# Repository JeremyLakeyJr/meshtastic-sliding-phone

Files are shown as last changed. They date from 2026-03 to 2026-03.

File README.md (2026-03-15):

# Meshtastic Sliding Phone

A 3D-printable sliding phone enclosure for **Meshtastic** mesh networking devices. This design houses a **Heltec WiFi LoRa 32 V4** board and a **M5Stack CardKB** I²C keyboard in a compact, pocket-friendly Nokia N900-style landscape slider. The keyboard tray slides along two rectangular guide rails on the interior side walls of the top shell, snapping into open and closed positions via offset neodymium magnet detents.

```
    ┌─────────────────────┐
    │  ╔═════════╗        │  ← Speaker grille
    │  ║ 0.96"   ║        │
    │  ║  OLED   ║        │  ← OLED viewport
    │  ╚═════════╝        │
    │     [PWR]  [VOL]    │  ← Side buttons
    ├─────────────────────┤  ← Rectangular rail guides (interior side walls)
    │  ┌─┐┌─┐┌─┐┌─┐┌─┐  │
    │  │Q││W││E││R││T│..  │  ← CardKB (revealed when slid open)
    │  └─┘└─┘└─┘└─┘└─┘  │
    │  ┌─┐┌─┐┌─┐┌─┐┌─┐  │
    │  │A││S││D││F││G│..  │
    │  └─┘└─┘└─┘└─┘└─┘  │
    │  [USB-C]    [ANT]   │  ← Ports
    └─────────────────────┘
```

## Features

- **Rectangular-rail slider** — two 3×3 mm rectangular guide rails on the interior side walls of the top shell constrain the keyboard tray; passive ~3° typing tilt at full extension
- **Offset magnetic detents** — 6× 10 mm × 4 mm neodymium disc magnets (4 in top shell, 2 in tray) snap audibly into closed and open positions via 6 mm lateral offset
- **0.96" OLED viewport** aligned with the Heltec V4's built-in 128×64 display
- **CardKB pocket** — snap-in slot for the M5Stack CardKB I²C keyboard module (88×54×7 mm)
- **LiPo battery** compartment (MakerFocus 3000 mAh or similar flat pouch cell, ~71×51×9 mm) integrated in the top shell
- **SMA antenna mount** with strain relief for LoRa whip antenna
- **USB-C port** access for charging and firmware flashing
- **Speaker grille & microphone** holes
- **Ventilation slots** for thermal management
- **M2 screw posts** for secure PCB mounting
- **Fully parametric** — all dimensions easily adjustable

## Improved CAD Generation Prompt

Use this prompt when generating enclosure concepts with AI CAD tools:

> Create a fully parametric, 3D-printable electronics enclosure optimized for FDM printing. Model separate printable parts (main shell, sliding tray, and mounting features), expose key dimensions as editable parameters (PCB size, battery size, wall thickness, clearances, and travel), and enforce print-safe geometry (minimum 2 mm walls, filleted/chamfered transitions, no unsupported overhangs beyond ~45°, and practical assembly tolerances). Include internal standoffs, cable-routing channels, ventilation, fastener or snap-fit options, and clear support for iterative dimension tuning without rewriting core geometry.

## Project Structure

```
meshtastic-sliding-phone/
├── models/
│   ├── scad/                    # OpenSCAD parametric source files
│   │   ├── parameters.scad      # Shared dimensions & tolerances
│   │   ├── utilities.scad       # Reusable shape modules (rails, magnets, etc.)
│   │   ├── top_shell.scad       # Unified top enclosure: OLED viewport, PCB bay, battery, rails
│   │   ├── keyboard_tray.scad   # Sliding keyboard tray: CardKB pocket, rail grooves, magnets
│   │   ├── bottom_shell.scad    # Alias for keyboard_tray.scad (2-piece naming)
│   │   ├── main_body.scad       # Backward-compatible alias for top_shell.scad
│   │   ├── antenna_mount.scad   # SMA connector mount with strain relief
│   │   └── assembly.scad        # Full exploded/assembled preview (not for printing)
│   └── stl/                     # Pre-generated printable meshes
│       ├── top_shell.stl
│       ├── keyboard_tray.stl
│       └── antenna_mount.stl
├── scripts/
│   └── generate_stl.py          # Python STL generator (no OpenSCAD needed; approximate)
├── docs/
│   └── bill_of_materials.md     # Parts list & sourcing guide
└── README.md
```

## Hardware Compatibility

| Component | Specification |
|---|---|
| **Main board** | Heltec WiFi LoRa 32 V4 (ESP32-S3 + SX1262 LoRa + 0.96" OLED) |
| **Display** | Built-in 0.96" OLED 128×64 (on Heltec V4 PCB) |
| **Keyboard** | M5Stack CardKB v1.1 (I²C, 88×54×7 mm, 46-key QWERTY) |
| **Battery** | MakerFocus 3.7 V LiPo 3000 mAh (~71×51×9 mm nominal) |
| **Antenna** | SMA LoRa antenna (868/915 MHz) |
| **Fasteners** | M2×8mm screws + M2 nuts |

## Dimensions

| Part | Width (X) | Length (Y) | Height (Z) |
|---|---|---|---|
| Top Shell | 95 mm | 120 mm | 19 mm |
| Keyboard Tray (Bottom Shell) | 95 mm | 120 mm | 8 mm |
| Antenna Mount | 16 mm | 12 mm | 10 mm |
| **Assembled (closed)** | **95 mm** | **120 mm** | **27 mm** |

Slider travel: **65 mm** (exposes full 54 mm CardKB short axis + margin)

## Getting Started

### Option 1: Use Pre-generated STL Files

The `models/stl/` directory contains ready-to-print STL files. Import them into your slicer (PrusaSlicer, Cura, etc.) and print.

### Option 2: Customize with OpenSCAD

1. Install [OpenSCAD](https://openscad.org/downloads.html)
2. Open any `.scad` file from `models/scad/`
3. Edit `parameters.scad` to adjust dimensions for your hardware
4. Render and export as STL

```bash
# Render individual parts from command line
openscad -o top_shell.stl models/scad/top_shell.scad
openscad -o keyboard_tray.stl models/scad/keyboard_tray.scad
openscad -o antenna_mount.stl models/scad/antenna_mount.scad
```

### Option 3: Generate STL with Python

No OpenSCAD required — uses `numpy-stl` for mesh generation:

```bash
pip install numpy-stl numpy
python3 scripts/generate_stl.py              # Generate all parts
python3 scripts/generate_stl.py --part top_shell  # Generate one part
```

## Print Settings

| Setting | Recommendation |
|---|---|
| **Layer Height** | 0.2mm (0.12mm for OLED viewport frame) |
| **Infill** | 20–25% top shell, 30% keyboard tray |
| **Material** | PETG or ASA recommended (PLA acceptable) |
| **Supports** | Not required — all overhangs ≤ 45°; rectangular groove walls need no support |
| **Orientation** | Top shell: display face down; keyboard tray: top face (grooves) down |
| **Walls** | 3 perimeters minimum |

## Assembly Instructions

1. **Print all parts** using recommended settings above
2. **Press-fit magnets** — press 6× 10 mm × 4 mm neodymium disc magnets into their pockets (check polarity: opposing pairs must attract). Top shell has 4 pockets (2 for closed snap at X=+38 mm, 2 for open snap at X=−39 mm); keyboard tray has 2 pockets at X=+32 mm.
3. **Seat the CardKB** — press the M5Stack CardKB module into the pocket in the keyboard tray; the retention ledges click it in place
4. **Mount the Heltec V4** — secure with M2×8mm screws through the 4 mounting posts inside the top shell; align the OLED with the viewport window
5. **Wire the CardKB** — run the CardKB I²C cable through the side access slot and connect to the Heltec V4 (SDA → GPIO 21, SCL → GPIO 22); use the wire routing groove alongside the rail
6. **Install the antenna mount** — attach to the top edge of the top shell with M2 screws, thread the SMA connector through
7. **Insert the LiPo battery** — place the flat LiPo cell in the battery compartment inside the top shell and snap the retention clips
8. **Assemble the slide** — align the keyboard tray's rail grooves with the top shell's rectangular rails at the **+X (right) end** and slide the tray in; it will snap into the closed position via the magnet detents
9. **Flash Meshtastic firmware** — connect via USB-C and use [flasher.meshtastic.org](https://flasher.meshtastic.org); select **Heltec WiFi LoRa 32 V4** as the target device

## Customization

All dimensions are parametric. Edit `models/scad/parameters.scad` to adjust:

- `phone_length`, `phone_width` — overall body footprint
- `wall_thickness` / `wall` — shell wall thickness (increase for durability)
- `clearance` — general sliding-fit tolerance (tune for your printer)
- `slider_travel` / `keyboard_travel` — how far the keyboard tray slides out (default 65 mm)
- `rail_width`, `rail_height` — rectangular guide rail cross-section (3×3 mm default)
- `rail_clearance` — per-side clearance between rail and tray groove (0.35 mm default)
- `rail_length` — guide rail length along X (70 mm default, ≥70% of tray width)
- `channel_standoff` — extra groove depth for passive typing tilt (2 mm → ~3° tilt)
- `magnet_offset` — lateral offset between body and tray magnet pockets for snap-in detent (6 mm)
- `corner_radius` — roundness of edges
- `cardkb_w`, `cardkb_h`, `cardkb_thickness` — CardKB module pocket dimensions
- PCB, battery, display viewport dimensions — match your specific hardware

## Contributing

Contributions welcome! Please:
- Test-print modified designs before submitting
- Update `parameters.scad` comments for new dimensions
- Include photos of printed parts if possible

## License

This project is open source. See individual files for details.

## Acknowledgments

- [Meshtastic](https://meshtastic.org/) — open-source mesh networking
- [Heltec Automation](https://heltec.org/) — WiFi LoRa 32 V4 hardware
- [M5Stack](https://m5stack.com/) — CardKB keyboard module
- OpenSCAD and numpy-stl communities

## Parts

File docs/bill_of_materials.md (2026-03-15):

# Bill of Materials — Meshtastic Sliding Phone

## Electronics

| Qty | Component | Specification | Notes |
|-----|---|---|---|
| 1 | Heltec WiFi LoRa 32 V4 | ESP32-S3 + SX1262 LoRa + built-in 0.96" OLED, 7 capacitive touch pins | Main controller board (51.7 × 25.4 mm, ≈52 × 26 mm) |
| 1 | M5Stack CardKB v1.1 | I²C QWERTY keyboard, 88×54×7 mm, 3.3 V/5 V | Connects to Heltec V4 via I²C (SDA/SCL) |
| 1 | LiPo Battery | 3.7 V, MakerFocus 3000 mAh flat pouch ~71×51×9 mm | JST PH 2.0 or JST 1.25 mm 2-pin connector |
| 1 | LoRa Antenna | SMA, 868 MHz or 915 MHz (region-dependent) | Stubby or flexible whip style |
| 1 | GPS Antenna | IPX/U.FL ceramic patch | Optional — Heltec V4 has no on-board GPS |

## Sliding Mechanism — Neodymium Disc Magnets

Six magnets total; install with poles oriented so opposing pairs **attract**.
Verify orientation before pressing in: wrong polarity will repel instead of snap.

| Qty | Component | Specification | Location |
|-----|---|---|---|
| 4 | Neodymium disc magnet | **10 mm dia × 4 mm thick, N35 grade** | Top shell — 2 × closed-snap pockets (body X=+38 mm), 2 × open-snap pockets (body X=−39 mm) |
| 2 | Neodymium disc magnet | **10 mm dia × 4 mm thick, N35 grade** | Keyboard tray — 2 × detent pockets (tray X=+32 mm) |

> **Magnet pocket spec**: Each pocket bore is 10.3 mm diameter × 3.6 mm deep with a 0.6 mm retention lip
> (entrance narrows to 9.1 mm). Press the 10 mm magnet past the lip — the FDM wall deflects slightly
> and springs back, locking the magnet in place. The magnet sits 0.4 mm proud of the face for better
> magnetic contact with the opposing pocket.
>
> **Detent offset**: Top-shell pockets are displaced ±6 mm in the slide direction (X) relative to the
> tray pockets. This offset creates an X-component attraction force that actively pulls the tray into
> each snap position rather than just providing a Z-axis normal force.

## Mechanical

| Qty | Component | Specification | Notes |
|-----|---|---|---|
| 8 | M2×8 mm screws | Pan head, Phillips or hex socket | PCB mounting + shell join |
| 8 | M2 hex nuts | Standard | Or use heat-set inserts |
| 4 | M2 heat-set inserts | 3.5 mm OD × 4 mm length | Optional — replaces nuts |
| 1 | Silicone grease | Small tube, PTFE-based | Apply to rail runners for smooth sliding |

## 3D Printed Parts

| Qty | Part | File | Material | Infill | Supports |
|-----|---|---|---|---|---|
| 1 | Top Shell | `top_shell.scad` | PETG / ASA | 20–25% | No |
| 1 | Keyboard Tray | `keyboard_tray.scad` | PETG / ASA | 30% | No — print top face DOWN |
| 1 | Antenna Mount | `antenna_mount.scad` | PETG / ASA | 40% | No |

> `bottom_shell.scad` is an alias for `keyboard_tray.scad` — they produce the same part.
> `main_body.scad` is a backward-compatible alias for `top_shell.scad`.

### Print orientation notes
- **Top shell**: display face down — button recesses and viewport print cleanly without support.
- **Keyboard tray**: top face (rail grooves) down — rectangular groove walls print as clean vertical layers; zero support needed.

## Assembly sequence

1. Press-fit magnets into the top-shell pockets (4 magnets; check polarity — closed-snap pair at X=+38 mm must attract tray magnets when tray is in closed position).
2. Press-fit magnets into the keyboard-tray pockets (2 magnets; opposing pole faces upward toward top shell).
3. Apply a thin coat of PTFE grease to the rectangular guide rails on the top shell.
4. Slide the keyboard tray in from the **+X (right) end** of the top shell.
   Hold the phone landscape (120 mm wide, 95 mm tall) — the keyboard slides
   downward to expose the CardKB, Nokia N900-style.
5. Snap the tray closed — the magnetic click should be clearly perceptible.
6. Assemble electronics: mount Heltec V4 PCB (51.7 × 25.4 mm) onto the 4 standoffs with M2 screws,
   route I²C cable from CardKB through the wire-routing groove and side access slot.
7. Insert the MakerFocus LiPo battery (71×51×9 mm) into the battery pocket; the retention clips snap over the edges.
8. Attach antenna mount to the top edge of the top shell with M2 screws and thread the SMA connector through.

## Optional Add-ons

| Component | Purpose |
|---|---|
| Wrist strap loop | Attach lanyard/strap for field use |
| Belt clip adapter | Clip to belt or MOLLE webbing |
| Capacitive touch overlay | 23 × 13 mm panel over OLED viewport; wire to V4 touch pins |
| Screen protector film | Cut to 23×13 mm for OLED/touch viewport |
| Rubber bumpers (4×) | Stick-on feet for table use |
| USB-C cable (short) | Charging / firmware flash |
| External GPS module | Add GPS capability (Heltec V4 has no on-board GPS) |

## Sourcing

- **Heltec WiFi LoRa 32 V4**: [Heltec Official Store](https://heltec.org/project/wifi-lora-32-v4/)
- **M5Stack CardKB v1.1**: [M5Stack Official Store](https://shop.m5stack.com/products/cardkb-mini-keyboard-programmable-unit-v1-1-mega328p)
- **MakerFocus 3000 mAh LiPo**: Search for "MakerFocus 3000mAh 3.7V lipo 71×51mm" on Amazon
- **10 mm × 4 mm N35 magnets**: Amazon / AliExpress — search "10mm x 4mm neodymium disc magnets N35"
- **M2 hardware**: Amazon, McMaster-Carr, local hardware store
- **PETG filament**: Prusament, eSun, Hatchbox or equivalent

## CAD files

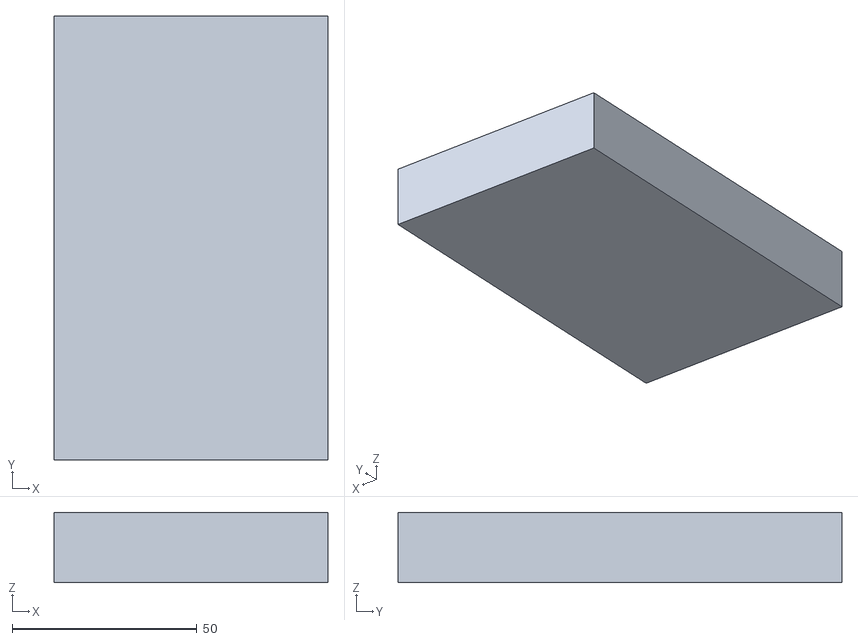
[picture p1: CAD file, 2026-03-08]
models/stl/main_body.stl
74.0 x 120.0 x 19.0

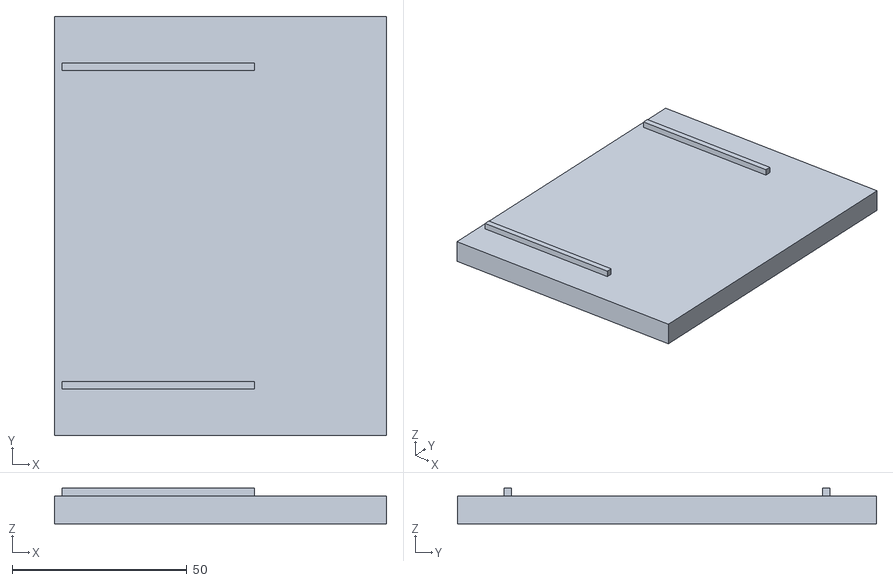
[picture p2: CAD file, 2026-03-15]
models/stl/keyboard_tray.stl
95.0 x 120.0 x 10.2

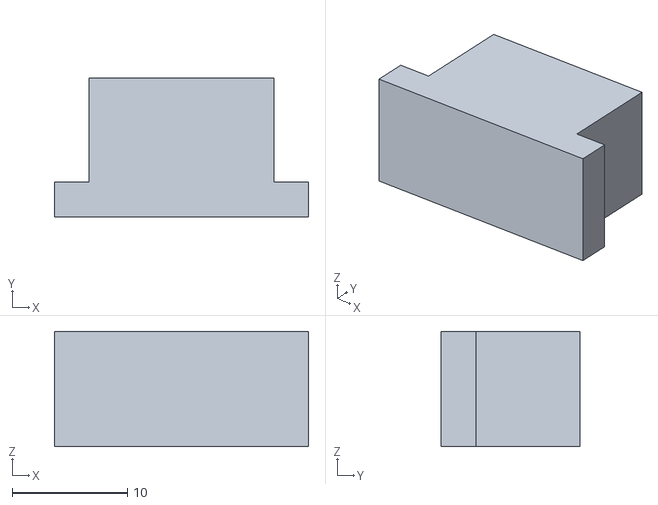
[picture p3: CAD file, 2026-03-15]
models/stl/antenna_mount.stl
22.0 x 12.0 x 10.0

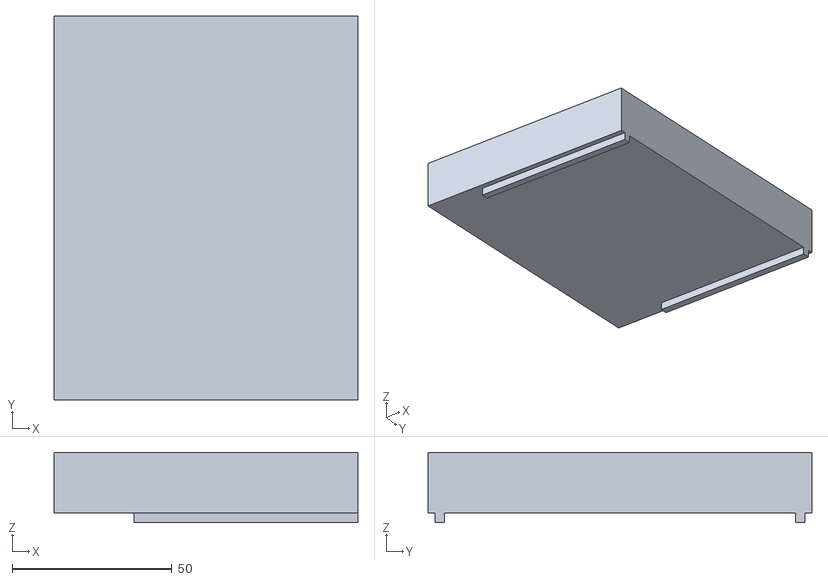
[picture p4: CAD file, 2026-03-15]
models/stl/top_shell.stl
95.0 x 120.0 x 22.0

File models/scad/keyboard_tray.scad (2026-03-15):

// ============================================================================
// Meshtastic Sliding Phone – Keyboard Tray  (sliding component / bottom shell)
// ============================================================================
// The horizontally sliding keyboard carriage.  Sits beneath the top shell
// and slides in the −X direction (shortways, along the 95 mm short axis) by
// slider_travel (65 mm) to expose the M5Stack CardKB module.  Holding the
// phone in landscape (120 mm wide × 95 mm tall) the keyboard slides downward.
//
// KEY FEATURES
// ─────────────────────────────────────────────────────────────────────────
// Slider rail grooves (capture the additive rails from the top shell)
//   The top shell carries two rectangular rails (rail_width × rail_height =
//   3 × 3 mm) on its interior side walls at Y = ±(phone_length/2 −
//   wall_thickness) = ±57.8 mm, protruding inward by rail_width.
//
//   The tray contains matching grooves that capture these rails:
//     Groove width  = rail_width  + 2 × rail_clearance = 3.7 mm  (Y span)
//     Groove depth  = rail_height + rail_clearance      = 3.35 mm (from top face)
//     Inner face    = wall_inner_y − rail_width − rail_clearance = 54.45 mm
//     Outer face    = wall_inner_y + rail_clearance             = 58.15 mm
//   The groove runs the same X range as the rails (runner_x_start … +47.5 mm).
//   Each groove is formed by:
//     (a) A guide block (additive) that fills the hollow interior near the
//         side wall, providing the groove floor and inner face.
//     (b) A clearance cut into the tray’s outer side wall (rail_clearance mm).
//
// Wire routing groove alongside +Y guide block
//   6 mm wide × 2 mm deep channel for the CardKB flex cable.
//
// Magnetic detents (neodymium disc magnets, 10 mm dia × 4 mm thick, N35)
//   Two press-fit pockets on the tray top face at ±magnet_y = ±20 mm,
//   X = +detent_x_offset = +32 mm (tray local).
//
// CardKB pocket (M5Stack CardKB v1.1, 88 × 54 × 7 mm)
//   Recessed pocket at the −X (extension) end.
//   Pocket: 89 × 55 mm (X × Y), depth = keyboard_pocket_depth = 8 mm.
//   Retention ledges on ±Y sides hold the CardKB in the pocket.
//
// VERTICAL CLEARANCE STACK (minimum 14 mm)
//   keyboard_thickness = 7 mm + tray_floor ≈ 2.2 mm + rail_height = 3 mm
//   + case_floor ≈ 2.2 mm = ~14.4 mm ≥ 14 mm spec ✓
//
// ─────────────────────────────────────────────────────────────────────────
// Assembly
//   1. Insert from the +X end: align the tray grooves with the top-shell
//      rails and slide −X until the closed-position magnet snap is felt.
//   2. Press-fit magnets (check pole orientation — opposing pairs attract).
//   3. Clip CardKB module into the tray pocket.
//
// Print orientation : TOP FACE DOWN (grooves print downward from tray face;
//                     no supports needed for rectangular groove walls)
// Print settings    : 0.2 mm layer height, 30 % infill, brim recommended
// ============================================================================

include <parameters.scad>
use <utilities.scad>

module keyboard_tray() {
    tray_w = phone_width;   // Tray X span matches top-shell body width (95 mm)

    // CardKB pocket dimensions (with clearance)
    pocket_x = cardkb_h + 2 * keyboard_clearance;   // 55 mm in X (slide direction)
    pocket_y = cardkb_w + 2 * keyboard_clearance;   // 89 mm in Y (long axis)

    // Groove X start: positioned at the +X (insertion) end of the tray.
    // Groove spans from (tray_w/2 − rail_length) to +tray_w/2.
    runner_x_start = tray_w/2 - rail_length;   // −22.5 mm (tray-local)

    // Slider rail groove geometry (per spec)
    // The top shell has rails at Y = ±wall_inner_y, protruding inward by rail_width.
    // Tray grooves capture these rails with rail_clearance on each side.
    wall_inner_y       = phone_length / 2 - wall_thickness;         // 57.8 mm
    groove_outer_y     = wall_inner_y + rail_clearance;              // 58.15 mm
    groove_inner_y     = wall_inner_y - rail_width - rail_clearance; // 54.45 mm
    slider_groove_depth = rail_height + rail_clearance;              // 3.35 mm
    slider_groove_width = rail_width  + 2 * rail_clearance;          // 3.70 mm

    union() {
        // ── Main tray body with all standard subtractions ──────────────────────────────
        difference() {
            // ── Main tray body ──────────────────────────────────────────────────────
            rounded_box(phone_width, phone_length, tray_z, corner_radius);

            // ── Interior cavity ─────────────────────────────────────────────────────
            // Open-bottom tray: hollow from wall_thickness up to tray_z.
            translate([0, 0, wall_thickness])
                rounded_box(phone_width  - 2 * wall_thickness,
                            phone_length - 2 * wall_thickness,
                            tray_z,
                            max(corner_radius - wall_thickness, 0.5));

            // ── CardKB module pocket (at the −X extension end) ───────────────────
            translate([-tray_w / 2 + wall_thickness + pocket_x / 2,
                       0,
                       wall_thickness])
                rounded_box(pocket_x, pocket_y, keyboard_pocket_depth, 2);

            // ── I²C / ribbon-cable relief slot (−X edge of tray) ─────────────────
            translate([-tray_w / 2 - 0.1,
                       0,
                       wall_thickness + cardkb_thickness / 2])
                rotate([0, 90, 0])
                    rounded_box(cardkb_thickness + 1, 10, wall_thickness + 0.4, 1);

            // ── Wire routing groove alongside +Y rail ───────────────────────────
            // Just inside the +Y guide block: Y = groove_inner_y − wire_tunnel_width − 0.5 mm gap
            translate([-tray_w / 2,
                       groove_inner_y - wire_tunnel_width - 0.5,
                       tray_z - wire_tunnel_height])
                cube([tray_w, wire_tunnel_width, wire_tunnel_height + 0.1]);

            // ── Magnet pockets on tray top face ──────────────────────────────────
            for (side = [-1, 1]) {
                translate([detent_x_offset,
                           side * magnet_y,
                           tray_z - magnet_depth])
                    magnet_pocket();
            }

            // ── Rail groove outer-wall clearance cut ───────────────────────────────
            // Removes rail_clearance (0.35 mm) from the outer side walls to provide
            // clearance between the groove outer face and the rail outer face.
            // Cut: Y = wall_inner_y … groove_outer_y = 57.8 … 58.15 mm (+Y side)
            //      mirrored for −Y side.
            for (flip = [false, true]) {
                mirror([0, flip ? 1 : 0, 0])
                    translate([runner_x_start - geom_epsilon,
                               wall_inner_y,
                               tray_z - slider_groove_depth - geom_epsilon])
                        cube([rail_length + 2 * geom_epsilon,
                              rail_clearance + geom_epsilon,
                              slider_groove_depth + 2 * geom_epsilon]);
            }
        }

        // ── Rail guide blocks with groove cuts ───────────────────────────────────
        // Each guide block fills the hollow interior adjacent to the outer side
        // wall.  After subtracting the groove interior, the block provides:
        //   • Groove floor  : solid from Z = wall_thickness to tray_z − groove_depth
        //   • Groove channel : hollow from Z = tray_z − groove_depth to tray_z
        //   • Inner face    : block face at Y = groove_inner_y (captures rail
        //                      inner face at Y = wall_inner_y − rail_width with
        //                      rail_clearance = 0.35 mm clearance)
        //
        // Guide block (additive):
        //   Y = groove_inner_y … wall_inner_y = 54.45 … 57.8 mm
        //   Z = wall_thickness … tray_z         = 2.2 … 8 mm
        //   X = runner_x_start … tray_w/2        = −22.5 … +47.5 mm
        //
        // Groove cut (subtracted from block):
        //   Y = groove_inner_y … wall_inner_y  (same as block width)
        //   Z = tray_z − groove_depth … tray_z = 4.65 … 8 mm
        for (flip = [false, true]) {
            mirror([0, flip ? 1 : 0, 0])
                difference() {
                    // Guide block
                    translate([runner_x_start,
                               groove_inner_y,
                               wall_thickness])
                        cube([rail_length,
                              wall_inner_y - groove_inner_y,
                              tray_z - wall_thickness]);
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

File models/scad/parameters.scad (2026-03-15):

// ============================================================================
// Meshtastic Sliding Phone – Shared Parameters
// ============================================================================
// All dimensions in millimeters.
//
// Form factor: landscape slider phone (Nokia N900-style).
//   Closed: 95 × 120 × 27 mm (X × Y × Z)   Open: ~160 × 120 × 27 mm
//
// Mechanism: the keyboard tray slides in the −X direction (shortways, along
// the 95 mm short axis) guided by two parallel captured rectangular rails.
// Holding the phone in landscape (120 mm horizontal, 95 mm vertical), the
// keyboard slides downward to expose the CardKB.
//
// Rail system: rectangular cross-section, rail_width=3 mm × rail_height=3 mm,
// additive on the interior side walls of the top shell.  Rail length = 70 mm
// (≥70 % of tray width, reduces cantilever flex).  Rails protrude BELOW the
// top-shell bottom face (Z = −rail_height … 0) and engage matching grooves
// in the keyboard tray.
//
// RAIL CROSS-SECTION (Y–Z plane, additive on top-shell interior wall):
//
//   ┌──────────────────┐  ← rail_width = 3 mm (Y protrusion from wall face)
//   │                  │
//   │                  │  ← rail_height = 3 mm (Z extent below shell face)
//   └──────────────────┘
//
// Tray groove (captures rail with rail_clearance = 0.35 mm per side):
//   Groove width  = rail_width  + 2 × rail_clearance = 3.7 mm
//   Groove depth  = rail_height + rail_clearance      = 3.35 mm
//
// Magnets: 10 mm × 4 mm neodymium disc, pockets 10.3 mm bore × 3.6 mm deep
// with 0.6 mm retention lip, 6 mm detent offset (creates X-axis snap force).
// Slider travel = 65 mm, exposing ≥ 60 mm of tray (full CardKB height).
//
// STRUCTURE (2-piece design)
//   top_shell     – unified enclosure: display, PCB, battery, rails, ports
//   keyboard_tray – sliding component: CardKB, rail grooves, magnets
//   (bottom_shell is an alias for keyboard_tray)
// ============================================================================

// --- Overall phone body footprint (closed) ---
phone_length    = 120;   // Y: body length
// phone_width = 95 mm: slider_travel(65) + rail_engagement(30) = 95  ✓
phone_width     =  95;   // X: body width

// --- Component heights (Z) ---
top_shell_z     =  10;   // Display / PCB section height
bot_shell_z     =   9;   // Battery / ports section height
body_z          = top_shell_z + bot_shell_z;  // 19 mm – unified top_shell height
tray_z          =   8;   // Keyboard tray height

// Total closed thickness (informational)
phone_thickness = body_z + tray_z;   // 27 mm

// --- Wall thickness and tolerances ---
wall_thickness  = 2.2;   // Minimum wall thickness (≥ 2 mm per spec)
wall            = wall_thickness;   // Backwards-compatible alias
clearance       = 0.3;   // General sliding-fit clearance per side (non-rail)
corner_radius   = 4.0;   // Rounded corner radius

// --- Display viewport (Heltec V4 built-in 0.96″ OLED, 128×64) ---
display_w        = 23;   // Viewable width
display_h        = 13;   // Viewable height
display_offset_y = 12;   // Distance from top edge of body to viewport centre
display_depth    =  2.0; // Countersink depth

// --- Heltec WiFi LoRa 32 V4 board (ESP32-S3 + SX1262 + 0.96″ OLED) ---
pcb_length      = 52;    // Board Y length
pcb_width       = 26;    // Board X width
pcb_thickness   =  1.6;  // PCB thickness
pcb_clearance   =  9;    // Component height above PCB

// PCB standoffs (M2 screws, Heltec V3/V4)
standoff_height   = 4.0;  // Standoff height
standoff_diameter = 6.0;  // Standoff outer diameter
screw_hole_d      = 3.0;  // Screw clearance hole diameter
standoff_floor_thickness = 1.5;  // Solid floor thickness beneath blind standoff hole

geom_epsilon = 0.1;     // Small overlap offset to prevent coincident-face artifacts

// --- PCB mounting platform (structural floor reinforcement under Heltec board) ---
platform_thickness = 2.0;  // Platform slab height above case floor

// --- USB-C port cutout ---
usbc_width  = 11.0;  // USB-C opening width
usbc_height =  4.0;  // USB-C opening height

// --- Battery pocket (MakerFocus 3000 mAh 3.7 V LiPo, ~71×51×9 mm) ---
battery_pocket_x =  71.0;  // Pocket X dimension
battery_pocket_y =  51.0;  // Pocket Y dimension
battery_pocket_z =   9.0;  // Pocket depth (Z)

// ============================================================================
// CardKB keyboard module (M5Stack CardKB v1.1, I²C)
// ============================================================================
// Physical board: 88 × 54 × 7 mm
//   cardkb_w  – long axis, runs along the phone Y-axis when installed
//   cardkb_h  – short axis, along the sliding X-axis
// Pocket sized with keyboard_clearance on all edges; depth = keyboard_pocket_depth.
// ============================================================================
cardkb_w         = 88;   // CardKB long axis (along phone Y)
cardkb_h         = 54;   // CardKB short axis (along sliding X)
cardkb_thickness =  7;   // CardKB height (Z)

// Keyboard fit parameters
keyboard_clearance    = 0.5;  // Per-side clearance around keyboard in X and Y
keyboard_pocket_depth = 8;    // Pocket depth (≥ cardkb_thickness + clearance)

// --- Keyboard slide travel ---
// slider_travel = 65 mm exposes the full 54 mm CardKB height plus margin.
// Exposed tray area at full extension = slider_travel = 65 mm ≥ 60 mm spec.  ✓
slider_travel    = 65;   // mm; fully exposes CardKB
keyboard_travel  = slider_travel;  // Backward-compatible alias

// ============================================================================
// Parallel captured rectangular rail system
// ============================================================================
// Two rectangular rails are additive features on the interior side walls of
// the top shell.  One rail along each long interior wall (Y = ±wall_inner_y),
// protruding inward by rail_width and running along the X axis for rail_length.
//
// Rail cross-section (Y–Z plane):
//   Width  : rail_width  = 3.0 mm (Y protrusion from the interior wall face)
//   Height : rail_height = 3.0 mm (Z extent below the top-shell bottom face)
//
// The rails protrude BELOW the top-shell bottom face (Z = −rail_height … 0).
// In world coordinates (top_shell placed at world Z = tray_z = 8 mm):
//   Rail world Z = tray_z − rail_height … tray_z = 5.0 … 8.0 mm
//
// Matching grooves in the keyboard tray capture the rails:
//   Groove width  = rail_width  + 2 × rail_clearance = 3.7 mm
//   Groove depth  = rail_height + rail_clearance      = 3.35 mm
//   Groove world Z = tray_z − groove_depth … tray_z  = 4.65 … 8.0 mm
//   Vertical clearance at groove floor = rail_clearance = 0.35 mm  ✓
//
// Rail placement:
//   Y = ±(phone_length/2 − wall_thickness)  (one per interior side wall)
//   X = phone_width/2 − rail_length … phone_width/2   (≥ 70 % of tray width)
//
// Rail length = 70 mm = 73.7 % of tray width (95 mm) ≥ 70 % spec  ✓
// ============================================================================
rail_height     = 3.0;   // Rail height (Z)
rail_width      = 3.0;   // Rail protrusion width from interior wall (Y)
rail_clearance  = 0.35;  // Per-side clearance between rail and tray groove
rail_length     = 70.0;  // Runner and groove length along X

// --- Wire routing tunnel (for keyboard flex cable alongside rail) ---
wire_tunnel_width  = 6.0;  // Tunnel width (Y direction)
wire_tunnel_height = 2.0;  // Tunnel height (Z direction)
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

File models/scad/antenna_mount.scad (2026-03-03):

// ============================================================================
// Meshtastic Sliding Phone - Antenna Mount
// ============================================================================
// Protective cap and strain relief for the SMA LoRa antenna connector.
// Attaches to the top edge of the bottom shell. Can be used with a
// stubby antenna or as a feed-through for an external whip antenna.
//
// Print settings: 0.2mm layer height, 40% infill
// ============================================================================

include <parameters.scad>
use <utilities.scad>

module antenna_mount() {
    mount_w    = 16;
    mount_l    = 12;
    mount_h    = 10;
    flange_h   = 3;
    flange_ext = 3;  // How far the flange extends past the shell wall

    difference() {
        union() {
            // --- Mount body ---
            rounded_box(mount_w, mount_l, mount_h, 2);

            // --- Flange (sits against inside of shell wall) ---
            translate([0, -mount_l/2 + flange_h/2, 0])
                rounded_box(mount_w + 2*flange_ext, flange_h, mount_h, 1.5);
        }

        // --- SMA connector through-hole ---
        translate([0, 0, mount_h/2 + 1])
            rotate([90, 0, 0])
                cylinder(h = mount_l + flange_h + 1, d = sma_diameter, center = true);

        // --- Wrench flat relief (hexagonal for SMA nut) ---
        translate([0, -mount_l/2 - 0.1, mount_h/2 + 1])
            rotate([90, 0, 0])
                cylinder(h = 3, d = sma_flat_width + 1, $fn = 6);

        // --- Screw mounting holes ---
        for (side = [-1, 1]) {
            translate([side * (mount_w/2 - 2), mount_l/2 - 3, -0.1])
                cylinder(h = mount_h + 0.2, d = screw_hole_d);
        }

        // --- Cable routing channel (bottom) ---
        translate([0, 0, 1])
            rotate([0, 90, 0])
                cylinder(h = mount_w + 1, d = 3, center = true);
    }
}

// --- Render ---
antenna_mount();

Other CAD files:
models/scad/assembly.scad
models/scad/bottom_shell.scad
models/scad/main_body.scad
models/scad/top_shell.scad
models/scad/utilities.scad

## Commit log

2026-03-03 Add 3D models for Meshtastic sliding phone enclosure
    - OpenSCAD parametric models (top shell, bottom shell, battery cover, antenna mount, assembly)
    - Python STL generator script using numpy-stl
    - Pre-generated STL files ready for 3D printing
    - Comprehensive README with assembly instructions
    - Bill of materials with sourcing guide
    [antenna_mount.scad, antenna_mount.stl, assembly.scad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]
2026-03-03 Fix ASL -> ASA typo in README print settings
2026-03-03 Update sliding phone design for CardKB keyboard and Heltec V4
    [assembly.scad, battery_cover.scad, bottom_shell.scad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]
2026-03-07 Replace dovetail slider with Sony Xperia-style arc guide mechanism
    - Replace linear dovetail rails with cylindrical guide pins on top shell
    - Replace dovetail channels with curved arc guide channels in bottom shell
    - Add snap detent notches at open/closed positions
    - Add arc slider parameters (arc_radius, tilt_angle, guide_pin_d, etc.)
    - Update assembly to demonstrate tilt when opened (slide_position param)
    - Update Python STL generator to produce guide pins and arc channels
    - Regenerate STL files with new mechanism
    - Update README and BOM documentation
    [antenna_mount.stl, assembly.scad, battery_cover.stl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]
2026-03-07 Address code review: extract magic numbers to named constants in STL generator, add comment in utilities.scad
    [antenna_mount.stl, battery_cover.stl, bottom_shell.stl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]
2026-03-07 Make both shells same size; fit MakerFocus 3000 mAh battery
    - Increase phone_length 120→165 mm so PCB+battery+keyboard all fit
    within the shared footprint with no component overlap
    - Set bot_shell_length = phone_length (was phone_length + keyboard_travel)
    so both shells are now 165×74 mm — identical when keyboard is slid in
    - Update battery to MakerFocus 3000 mAh 3.7 V (~65×36×10 mm):
    lipo_thickness 6→12 mm, lipo_width 35→38 mm, lipo_length 51→67 mm
    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
    [antenna_mount.stl, battery_cover.stl, bottom_shell.stl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]
2026-03-07 Implement horizontal magnetic-detent slider with parallel rail guides and phone-sized form factor
    [antenna_mount.stl, assembly.scad, battery_cover.scad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]
2026-03-07 Fix slide direction to shortways (X-axis) and integrate Heltec V4 touch screen
    [antenna_mount.stl, assembly.scad, battery_cover.stl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]
2026-03-07 Refactor: T-slot rails, rail_clearance, wall_thickness, press-fit magnets, stop walls, tab params
    [antenna_mount.stl, battery_cover.stl, bottom_shell.scad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]
2026-03-07 Resize magnet holes for 10x4 mm disc magnets
    [keyboard_tray.scad, parameters.scad, utilities.scad]
2026-03-07 Refactor: 2-piece enclosure (main_body + keyboard_tray) with snap-ramp and magnetic detents
    [antenna_mount.stl, assembly.scad, battery_cover.scad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]
2026-03-08 thicken slide rails for stability: rail_w 4→6mm, rail_h 2.5→3.5mm, rail_lip_w 1.5→2mm
    [parameters.scad, utilities.scad]
2026-03-08 Refactor slider mechanism: rail 3×2mm, 10mm magnets, 65mm travel, CardKB 88×54mm, top_shell.scad, bottom_shell.scad
    [antenna_mount.stl, assembly.scad, bottom_shell.scad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]
2026-03-08 refactor: dovetail rails, battery pocket 71x51x9mm, USB-C 11x4mm, 4mm standoffs, wire tunnel 6x2mm, progressive clearance
    [antenna_mount.stl, assembly.scad, keyboard_tray.scad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]
2026-03-08 implement magnet offset, rail length, standoff fix, platform, battery clips, lightening pockets
    [antenna_mount.stl, assembly.scad, keyboard_tray.scad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]
2026-03-08 Add improved CAD generation prompt to README
    [top_shell.stl]
2026-03-08 Revert regenerated STL artifact
    [top_shell.stl]
2026-03-08 fix: enforce sealed enclosure floor and blind standoffs
    [parameters.scad, top_shell.scad]
2026-03-08 refactor: parameterize blind-hole floor and interior side rails
    [parameters.scad, top_shell.scad]
2026-03-08 fix: finalize parametric sealed enclosure geometry
    [parameters.scad, top_shell.scad]
2026-03-08 Initial plan: implement slider rail constraints
    [top_shell.stl]
2026-03-08 Implement slider rail constraints: additive rails on interior side walls
    [antenna_mount.stl, assembly.scad, keyboard_tray.scad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]
2026-03-08 Final STL validation artifacts
    [antenna_mount.stl, keyboard_tray.stl, top_shell.stl]
2026-03-08 Initial plan
    [antenna_mount.stl, keyboard_tray.stl, top_shell.stl]
2026-03-08 Fix model: rail Z position, display top plate, magnet offsets, missing features, param mismatches
    [antenna_mount.stl, keyboard_tray.stl, main_body.scad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]
2026-03-15 Fix docs, BOM, and STL generator to match actual rectangular-rail design
    - README.md: correct mechanism description (rectangular rails, not arc/Xperia
    style), fix project structure (remove non-existent battery_cover.scad), fix
    all dimensions (95×120×27mm assembled vs wrong 74×165×24mm), fix hardware
    specs (CardKB 88×54×7mm, battery 71×51×9mm), fix assembly instructions
    (insert tray from +X end, no arc channels), fix customization parameters
    (remove arc_radius/tilt_angle/guide_pin_*, add actual rail/magnet params),
    fix print settings (no supports required for rectangular grooves)
    - docs/bill_of_materials.md: fix magnet specs (10mm×4mm N35, not 5mm×2mm N42;
    6 total not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
    [antenna_mount.stl, keyboard_tray.stl, top_shell.stl]
2026-03-15 Redo project: clean up dead code, fix all inconsistencies
    - parameters.scad: fix header (rectangular rail, not dovetail), remove ~40
    dead/legacy params (rail_base_width, rail_top_width, rail_angle, rail_y,
    channel_standoff, stop_block/tab_stop params, legacy lipo params, unused
    aliases, etc.), correct detent_x_offset comment block
    - utilities.scad: remove dead dovetail modules (rail_runner, rail_channel_void,
    wire_routing_groove) — rectangular rail design uses plain cubes, not these
    - main_body.scad: replace 235-line divergent implementation with a true alias
    that includes top_shell.scad and delegates to top_shell()
    - keyboard_tray.scad: fix wire routing groove Y position —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
    [antenna_mount.stl, keyboard_tray.scad, keyboard_tray.stl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]
